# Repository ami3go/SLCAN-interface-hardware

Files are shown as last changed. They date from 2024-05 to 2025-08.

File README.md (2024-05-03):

# SLCAN-interface-hardware
 Harware adapter for SLCAN interface based on MCP2515 and Arduino micro
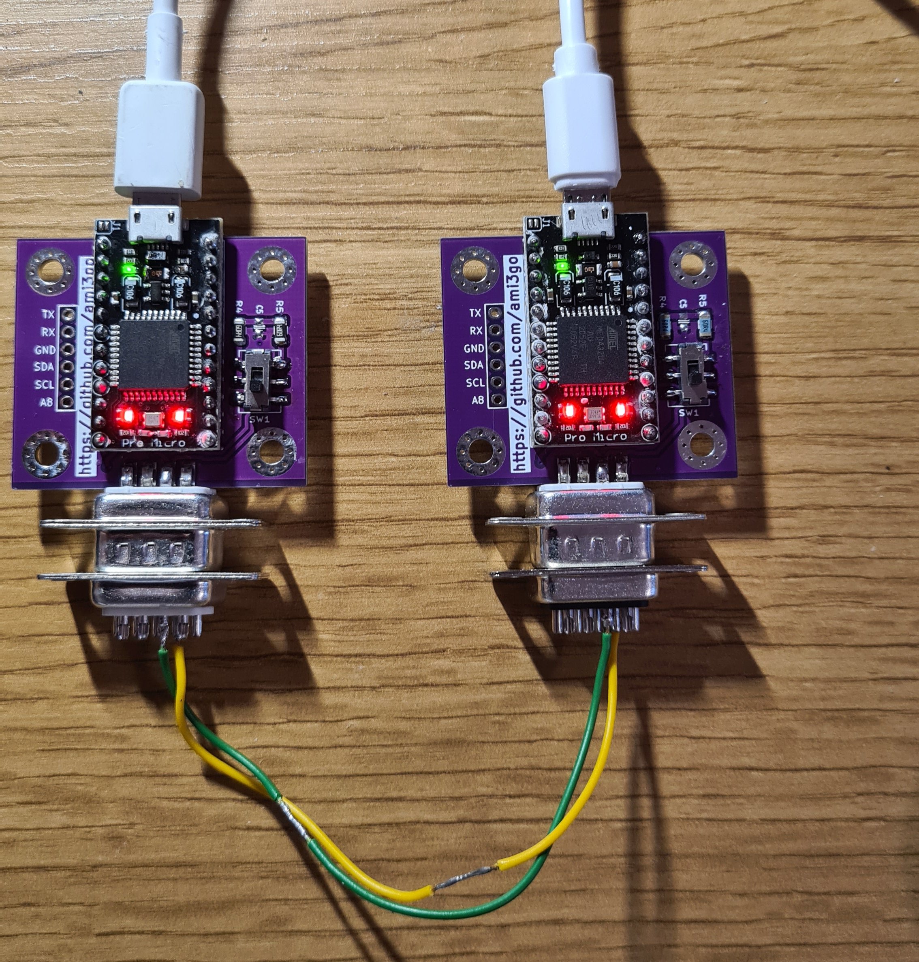
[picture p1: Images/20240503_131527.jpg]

 Those 3 project are connected: 
 - https://github.com/ami3go/SLCAN-python-examples
 - https://github.com/ami3go/SLCAN-interface-hardware
 - https://github.com/ami3go/SLCAN-interface-firmware

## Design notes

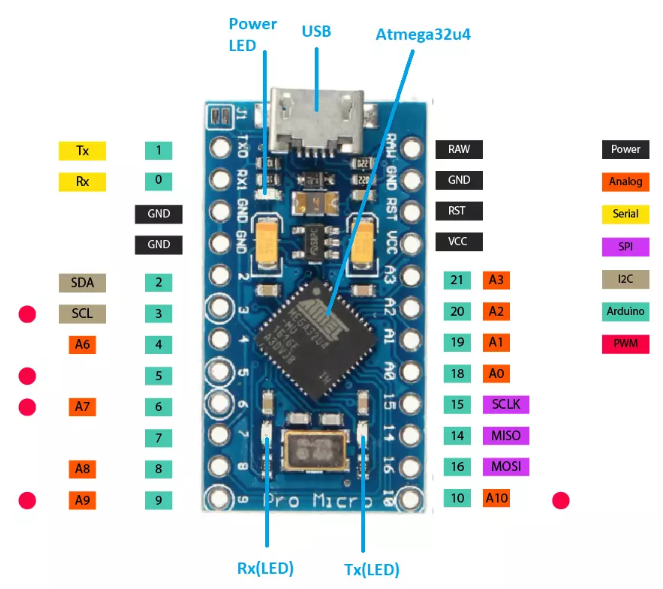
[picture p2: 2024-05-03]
Images/Introduction-to-Arduino-Pro-Micro-2.png

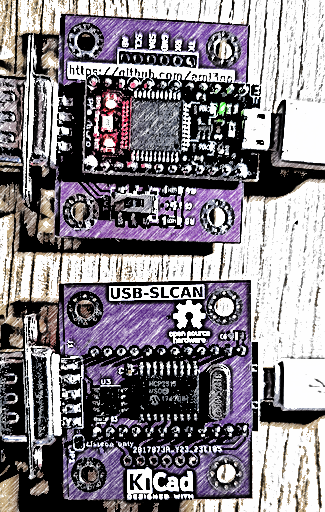
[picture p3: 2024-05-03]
Images/cover_photo.jpg

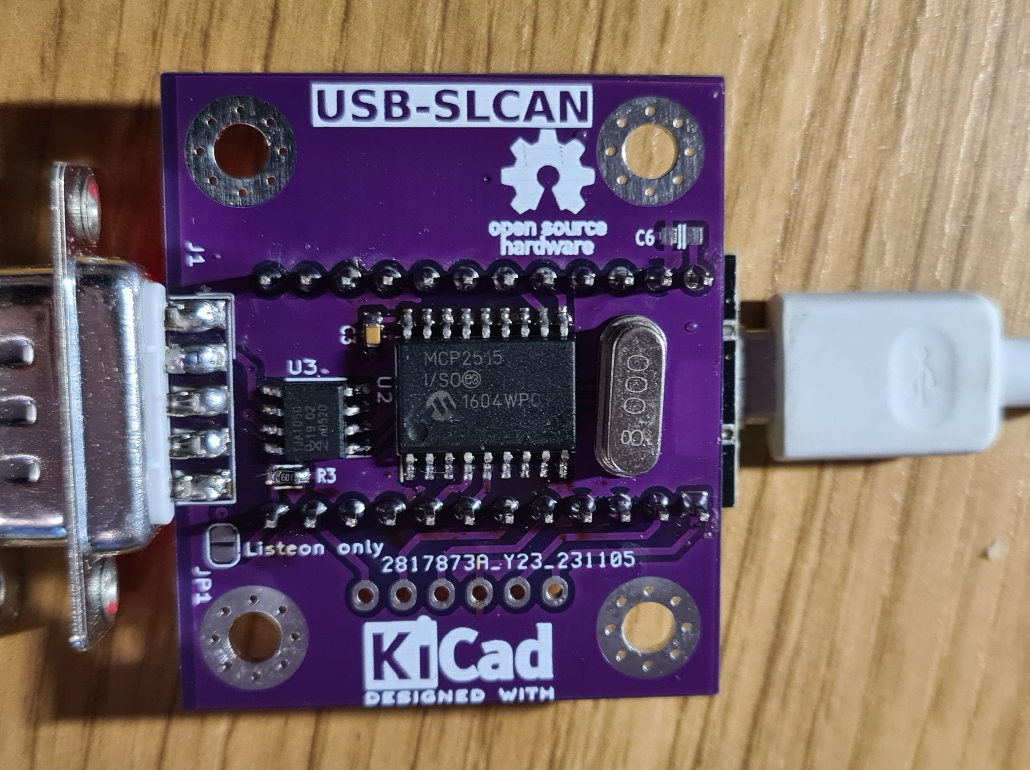
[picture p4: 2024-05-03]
Images/Pasted image.png

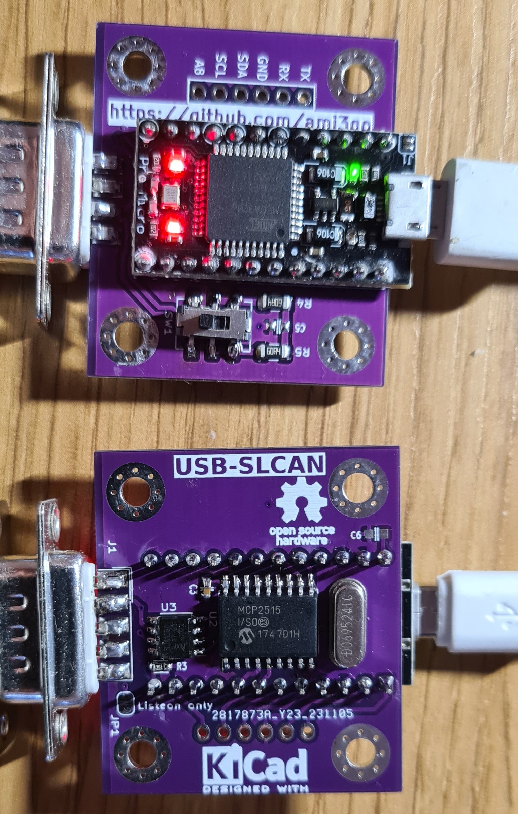
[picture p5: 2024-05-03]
Images/20240503_133706 (Copy).jpg

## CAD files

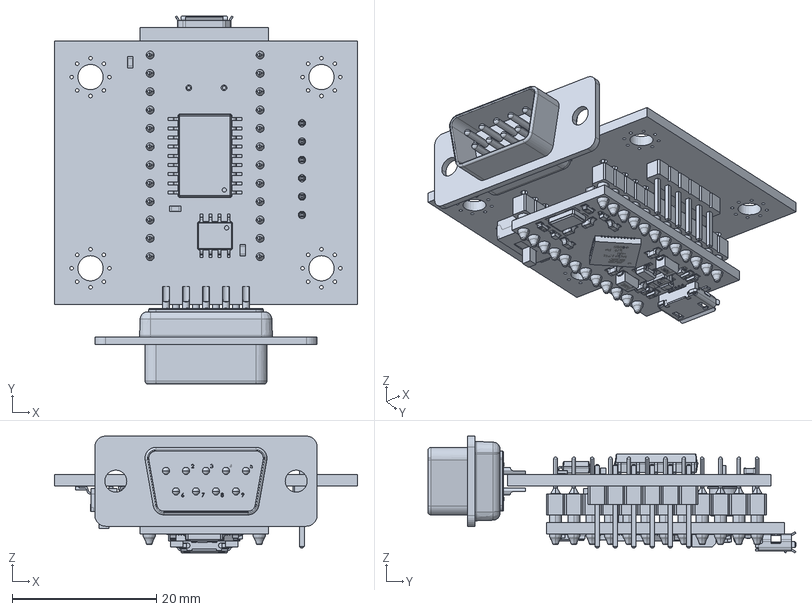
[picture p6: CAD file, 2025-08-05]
Eclosure/PCBa.FCStd
42.0 x 51.0 x 16.2 mm

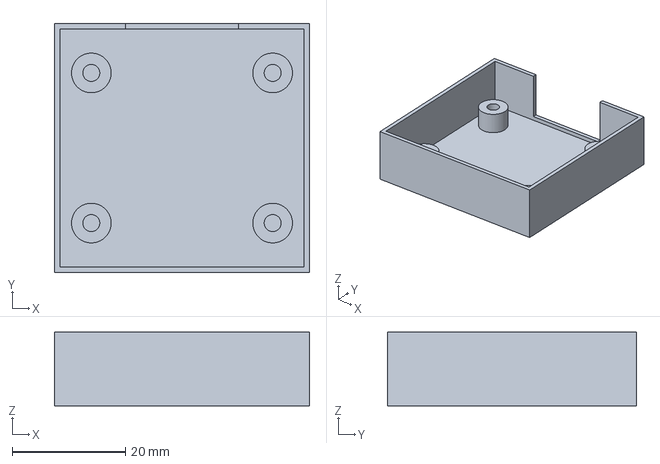
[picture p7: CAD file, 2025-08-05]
Eclosure/Part_1.FCStd
45.0 x 44.0 x 13.0 mm

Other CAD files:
Eclosure/Assebly.FCStd

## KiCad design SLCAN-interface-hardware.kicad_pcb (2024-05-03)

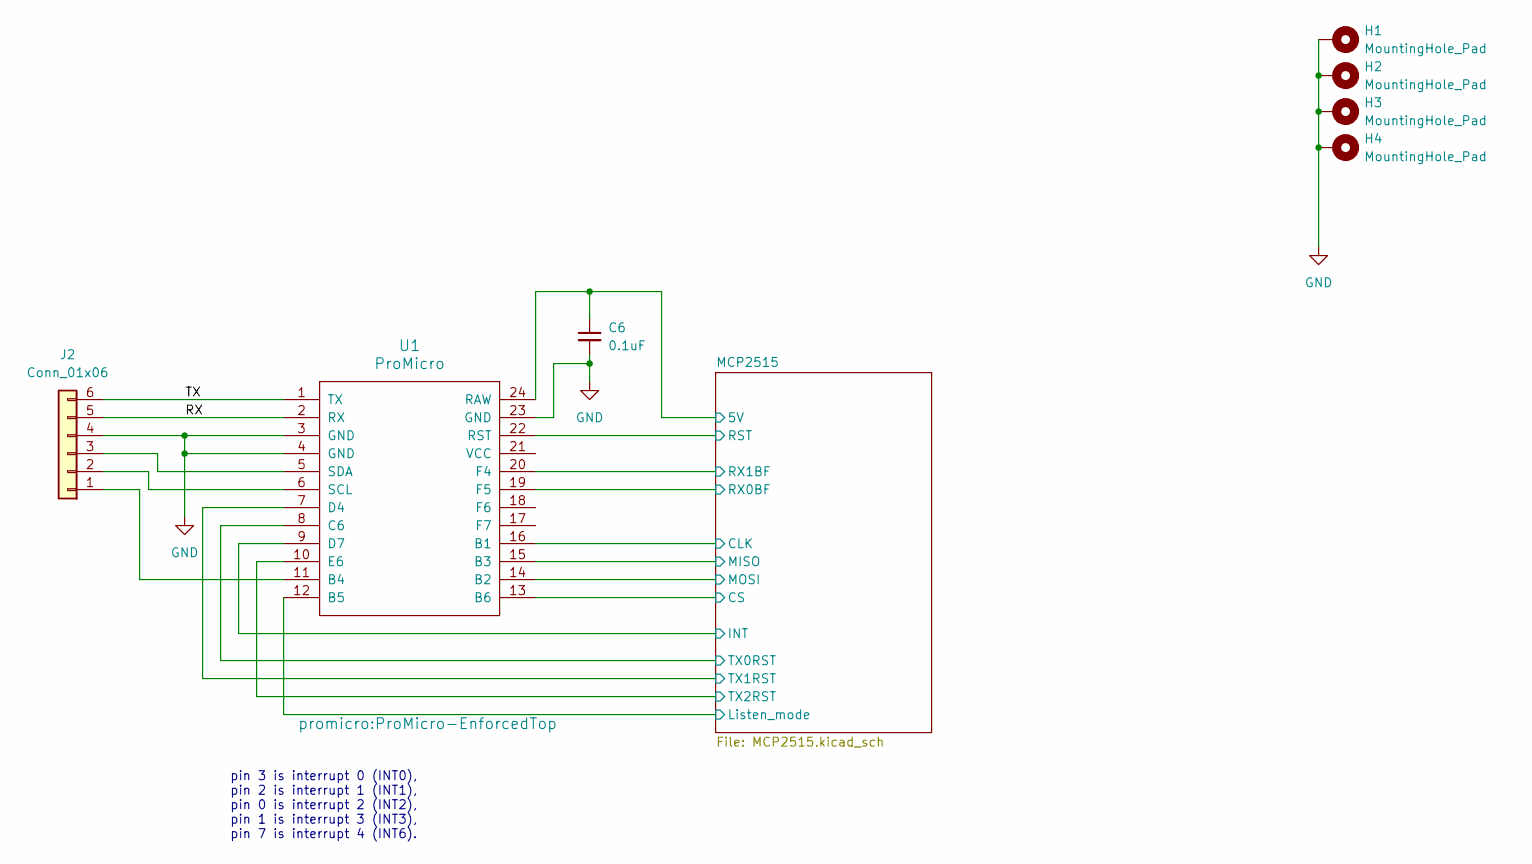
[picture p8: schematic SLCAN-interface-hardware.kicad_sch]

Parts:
C6: 100nF_0603_16V; C_0603; Part Number 0603YC104KAT2A; JLCPCB ID C14663
H1, H2, H3, H4: MountingHole_Pad; MountingHole_3.5mm_Pad_Via
J2: Conn_01x06; Pins_1x06_2.54mm_TH_SWD; Part Number 1-0601FBV0T
U1: ProMicro; ProMicro-EnforcedTop

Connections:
/MCP2515/5V: C6.1, U1.24 (RAW); also elsewhere on the board
/MCP2515/CLK: U1.16 (B1); also elsewhere on the board
/MCP2515/CS: U1.13 (B6); also elsewhere on the board
/MCP2515/INT: U1.9 (D7); also elsewhere on the board
/MCP2515/Listen_mode: U1.12 (B5); also elsewhere on the board
/MCP2515/MISO: U1.15 (B3); also elsewhere on the board
/MCP2515/MOSI: U1.14 (B2); also elsewhere on the board
/MCP2515/RST: U1.22 (RST); also elsewhere on the board
/MCP2515/RX0BF: U1.19 (F5); also elsewhere on the board
/MCP2515/RX1BF: U1.20 (F4); also elsewhere on the board
/MCP2515/TX0RST: U1.8 (C6); also elsewhere on the board
/MCP2515/TX1RST: U1.7 (D4); also elsewhere on the board
/MCP2515/TX2RST: U1.10 (E6); also elsewhere on the board
/RX: J2.5, U1.2 (RX)
/TX: J2.6, U1.1 (TX)
GND: C6.2, H1.1, H2.1, H3.1, H4.1, J2.4, U1.3 (GND), U1.4 (GND), U1.23 (GND); also elsewhere on the board
unnamed: J2.1, U1.11 (B4)
unnamed: J2.2, U1.6 (SCL)
unnamed: J2.3, U1.5 (SDA)

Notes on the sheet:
pin 3 is interrupt 0 (INT0), pin 2 is interrupt 1 (INT1), pin 0 is interrupt 2 (INT2), pin 1 is interrupt 3 (INT3), pin 7 is interrupt 4 (INT6).

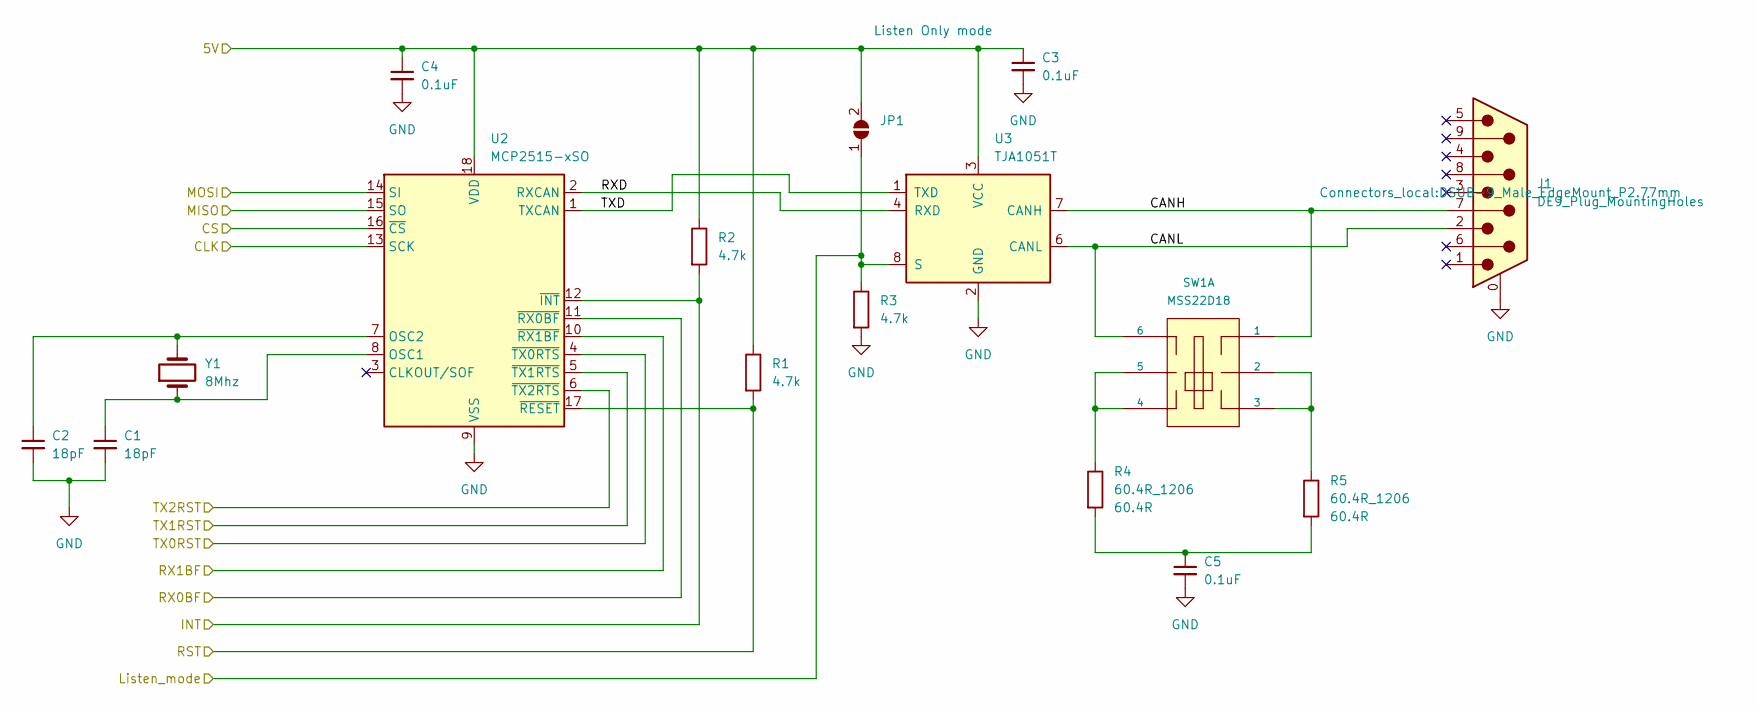
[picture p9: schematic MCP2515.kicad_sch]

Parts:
C1, C2: 18pF_0603_50V; C_0603; Part Number C0603C180J5GACTU; JLCPCB ID C1647
C3, C4, C5: 100nF_0603_16V; C_0603; Part Number 0603YC104KAT2A; JLCPCB ID C14663
J1: DE9_Plug_MountingHoles; DSUB-9_Male_EdgeMount_P2.77mm
JP1: SolderJumper_2_Open; SolderJumper-2_P1.3mm_Open_RoundedPad1.0x1.5mm
R1, R2, R3: 4.7k_0603; R_0603; Part Number RC0603FR-074K7L; JLCPCB ID C23162
R4, R5: 60.4R_1206; R_1206_3216Metric; Part Number CR1206-FX-60R4ELF
SW1: MSS22D18; Part Number MSS22D18
U2: MCP2515-xSO; SOIC-18W_7.5x11.6mm_P1.27mm
U3: TJA1051T; SOIC-8_3.9x4.9mm_P1.27mm
Y1: 8Mhz; Crystal_HC49-4H_Vertical

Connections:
/MCP2515/5V: C3.1, C4.1, JP1.2 (B), R1.1, R2.1, U2.18 (VDD), U3.3 (VCC); also elsewhere on the board
/MCP2515/CANH: J1.7, SW1.1, U3.7 (CANH)
/MCP2515/CANL: J1.2, SW1.6, U3.6 (CANL)
/MCP2515/CLK: U2.13 (SCK); also elsewhere on the board
/MCP2515/CS: U2.16 (~CS); also elsewhere on the board
/MCP2515/INT: R2.2, U2.12 (~INT); also elsewhere on the board
/MCP2515/Listen_mode: JP1.1 (A), R3.1, U3.8 (S); also elsewhere on the board
/MCP2515/MISO: U2.15 (SO); also elsewhere on the board
/MCP2515/MOSI: U2.14 (SI); also elsewhere on the board
/MCP2515/RST: R1.2, U2.17 (~RESET); also elsewhere on the board
/MCP2515/RX0BF: U2.11 (~RX0BF); also elsewhere on the board
/MCP2515/RX1BF: U2.10 (~RX1BF); also elsewhere on the board
/MCP2515/RXD: U2.2 (RXCAN), U3.4 (RXD)
/MCP2515/TX0RST: U2.4 (~TX0RTS); also elsewhere on the board
/MCP2515/TX1RST: U2.5 (~TX1RTS); also elsewhere on the board
/MCP2515/TX2RST: U2.6 (~TX2RTS); also elsewhere on the board
/MCP2515/TXD: U2.1 (TXCAN), U3.1 (TXD)
GND: C1.2, C2.2, C3.2, C4.2, C5.2, J1.0 (PAD), R3.2, U2.9 (VSS), U3.2 (GND); also elsewhere on the board
unnamed: C5.1, R4.2, R5.2
unnamed: R4.1, SW1.4, SW1.5
unnamed: R5.1, SW1.2, SW1.3
unnamed: C1.1, U2.8 (OSC1), Y1.1
unnamed: C2.1, U2.7 (OSC2), Y1.2

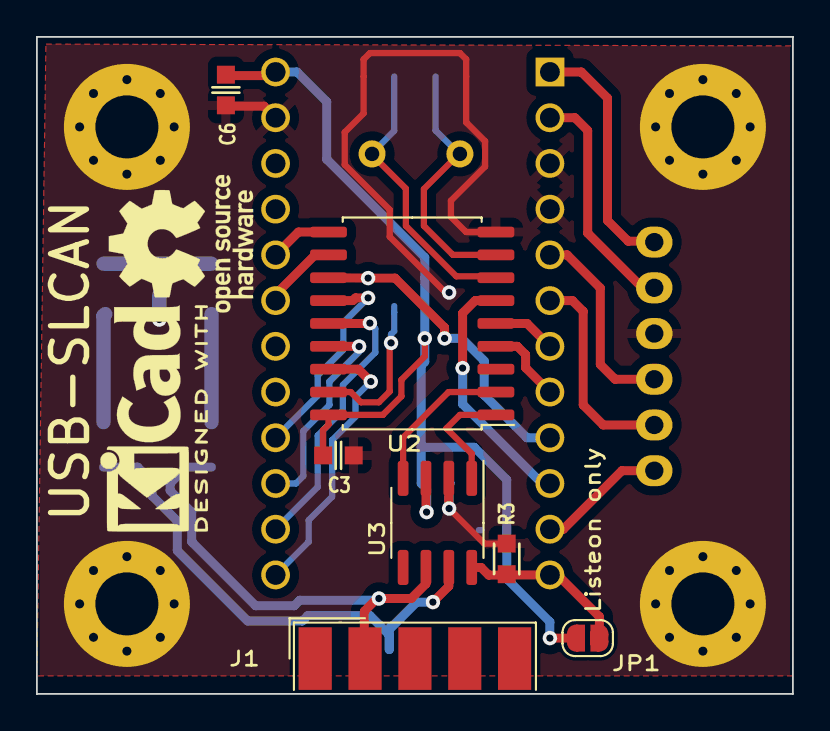
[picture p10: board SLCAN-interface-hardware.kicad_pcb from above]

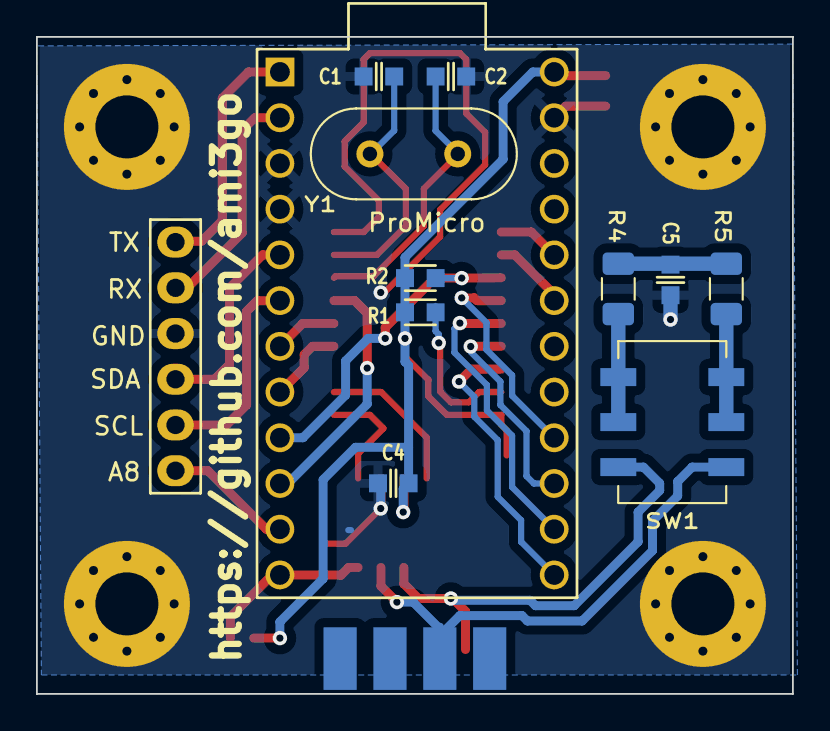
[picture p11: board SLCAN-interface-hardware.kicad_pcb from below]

Board: 2 copper layers, 42.0 x 36.5 mm, 23 parts (12 on the bottom side), 28 nets.

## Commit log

2024-05-03 Add step model
    [SLCAN-interface-hardware.kicad_pcb]
2025-08-05 Start working on enclosure
    [Assebly.FCStd, PCBa.FCStd, Part_1.FCStd]
